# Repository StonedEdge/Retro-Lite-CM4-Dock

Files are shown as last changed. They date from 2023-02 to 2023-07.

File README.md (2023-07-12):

<div align="center">

# **Retro Lite CM4 AIO Docking Station**

</div>

<p align="center">
   
</p>
<p align="center">
   
</p>
<p align="center">
   
</p>

# Description 
Updated: 2023/07/09

Note: Code base is now functional in terms of splashscreen, statistics images and metadata with text wrap! 
I'm considering this project completed at this stage. Feel free to make improvements to it and use it in any way you'd like! 

-----------------------------------------------------------------------------------------------------------

The Retro Lite CM4 docking station/hub is designed to be used with the Retro Lite CM4 gaming console however will work on any generic Linux host running RetroPie. 
The main goal of this project is to act as a metadata box for your RetroPie system & learn more about the games you are playing in real time - the aim is to preserve a small part of retro gaming history through this project. The project boasts the following features:

- Fully integrated 1.5" 128x128 SPI driven 16-bit color display 
- 3 modes, including **splashscreen**, **stats** and **game** mode. Navigation is done using a push button connected to a GPIO pin
- 3 x external USB 2.0 ports to use for keyboard, mouse & other peripherals in desktop mode. USB controller compatible for low latency
- USB-C charging 
- HDMI video output 

Here is the general flow of the program and how it works when power is applied:

1) **Splashscreen mode**
   - Splashscreen is played until EmulationStation starts. After which, stats mode is entered
2) **Stats mode**
   - Shows general system statistics - IP address, SoC temperature, RAM usage, etc. Stats are updated in 5 second intervals
   - Retro stats - see your systems overall top 5 games played by (a) duration and (b) times played 
3) **Game mode**
   - Shows a combined image of the game being played on launch of any game
   - Cycle through 5 different metadata views via the push button attached to the docking station. These are: 

         a) Combined vector image of wheel and screenshot

         b) Official game boxart

         c) A randomized vector image of the real hardware the game could be played on. Includes all variants of every console (shoutouts to Ampersand for providing the high quality vectors!)

         d) A description of the game, which scrolls vertically along the display

         e) Other metadata, including rating, release date, developer, publisher, genre & # players per game 

# Installation
To install, run (won't currently work yet!)
```
git clone https://github.com/StonedEdge/Retro-Lite-CM4-Dock.git
sudo chmod +x install_dock.sh
./ install_dock.sh
```

I recommend scraping your media files via the inbuilt scraper in the RetroPie setup script menus. This will download all of the metadata required and automatically store it in /home/pi/RetroPie/roms/{system_name}/media. 

# Metadata directory locations 

a) **Current game cover (boxart)** - /opt/retropie/configs/all/emulationstation/downloaded_images/{system}/{rom_name}.png

b) **Screenshot + combined wheel image** - /home/pi/retropie/roms/{system}/media/wheel/{rom_name}.png && /home/pi/retropie/roms/{system}/media/screenshot/{rom_name}.png

c) **Randomized vector images of console released** - /home/pi/pico/pico-examples/pico-spi/consolevectors

d) **Game description using vertical scrolling** - /opt/retropie/configs/all/emulationstation/gamelists', system_name, 'gamelist.xml'

e) **Game developer** - /opt/retropie/configs/all/emulationstation/gamelists', system_name, 'gamelist.xml' 

f) **Release date** - /opt/retropie/configs/all/emulationstation/gamelists', system_name, 'gamelist.xml'

g) **Videos** - /home/pi/retropie/roms/{system}/media/videos/{rom_name}.mp4

# Hardware 
Image of Retro Lite CM4

Pinout to connect the OLED screen to the docking station is located above. Gerbers and CAD (both docking station and separate OLED box) files will be updated soon once the software is completed. 

# To-do
- [x] Detect current game/system booted using `runcommand`
- [x] Add Retrolite CM4 splashscreen on boot 
- [x] Downscale + convert screenshot and wheel images to 128x128 RGB565 on Pi 4 (Python)
- [x] Detect RP2040 by Product/Vendor IDs (VID/PIDs)  
- [x] Identify how to extract game text metadata using Python 
- [x] Send system stats to RP2040 over USB 
- [x] Clear buffer when runcommand-onend.sh is executed when a game is closed, bringing back user to Pi stats view
- [x] Stop splashscreen on COM port detect and switch to stats mode
- [x] Send over RGB565 combined.png over serial without corruption, automatic switching from Pi stats to current game
- [x] Write a python script to scale the boxart correctly to fit the screen
- [x] Send over random image to Pico located in consolevectors based on current system being launched on RetroPie (no scaling necessary)
- [x] Implement a button state machine to switch between the stats and image mode
- [x] Implement a timeout which fades black to the OLED with no button input. Wake up OLED on button press after X mins of no activity 
- [x] Implement game metadata within game mode
- [x] Gracefully shutdown the OLED display when the console is powered down and restart it when console is repowered on
- [x] Identify how to perform hardware (or software) vertical scrolling of text on the SSD1351 for game descriptions 
- [x] Fix some new line errors in metadata mode 
- [x] Figure out how to encode special characters - probably via European code pages (CP1250/1252)

# Nice to have/probably won't implement any time soon! 
- [ ] Write a python script to break up video into individual video frames on the Pi 4 
- [ ] Setup tinyUSB library to try and achieve 0.9MB/s transfer speeds for all frames, for 30 FPS video over USB 1.1 (max 1.5MB/s)
- [ ] Implement "retrostats" into stats mode to show user most played games by **times played** & **time duration** using the RetroStats scripts. Note : No RTC so time duration may not be accurate.

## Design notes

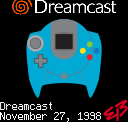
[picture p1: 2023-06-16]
consolevectors/dreamcast/Dreamcast - Electronics Botique.png

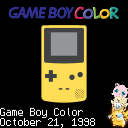
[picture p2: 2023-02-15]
consolevectors/gbc/Game Boy Color - Special Pikachu Edition.png

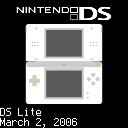
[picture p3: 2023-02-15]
consolevectors/nds/Nintendo DS Lite - White.png

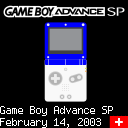
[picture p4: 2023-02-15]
consolevectors/gba/GBA SP -Swarovski (US).png

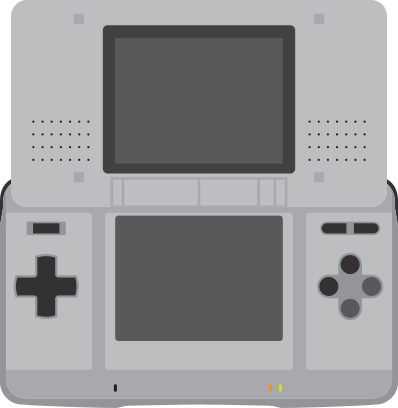
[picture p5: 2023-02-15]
consolevectors/nds/DS.png

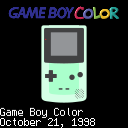
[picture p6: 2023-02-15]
consolevectors/gbc/Game Boy Color - Clear Green (Toys 'R' Us, Japan, 2000).png

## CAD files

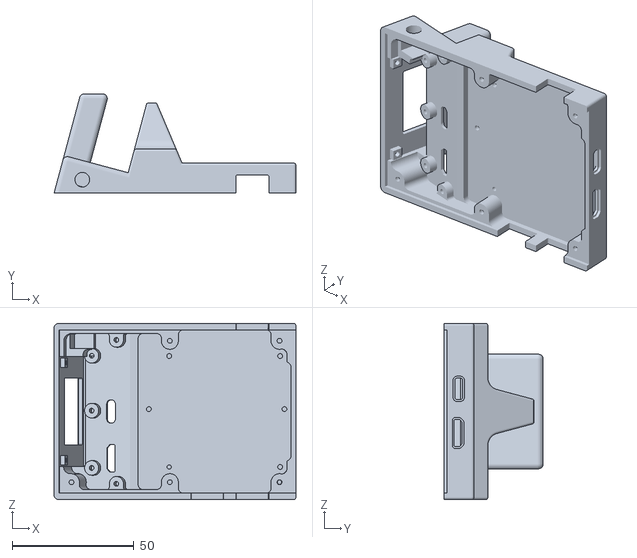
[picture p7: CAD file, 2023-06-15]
CAD/Dock - Main Housing.stl
99.2 x 40.8 x 72.3

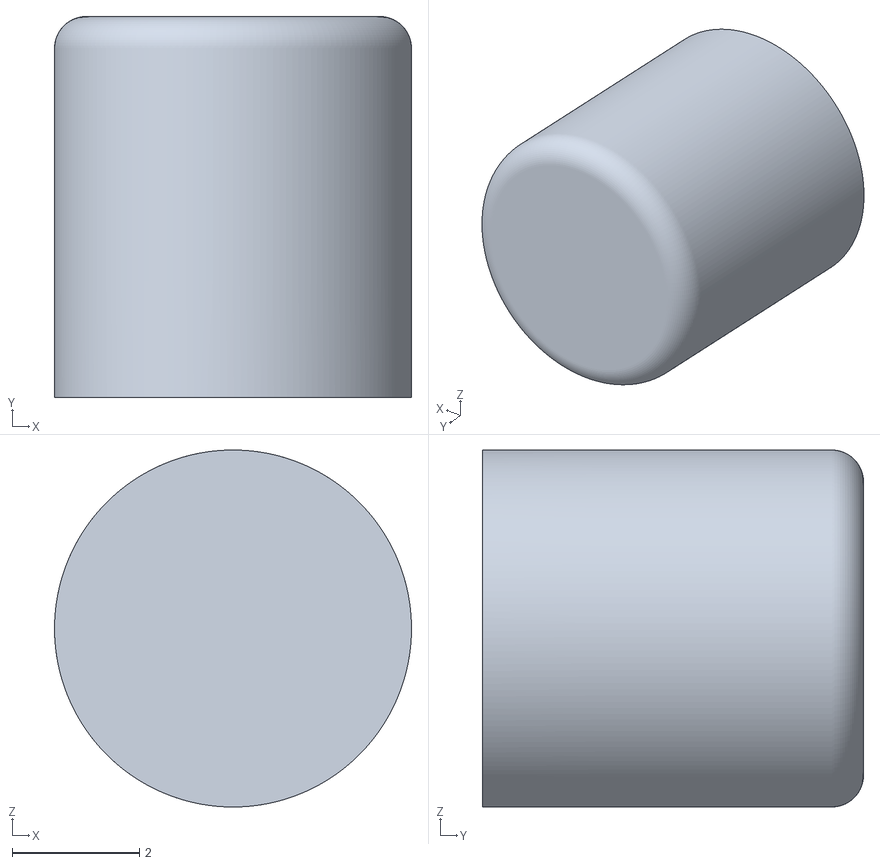
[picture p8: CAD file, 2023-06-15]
CAD/Button.stl
5.62 x 6.00 x 5.62

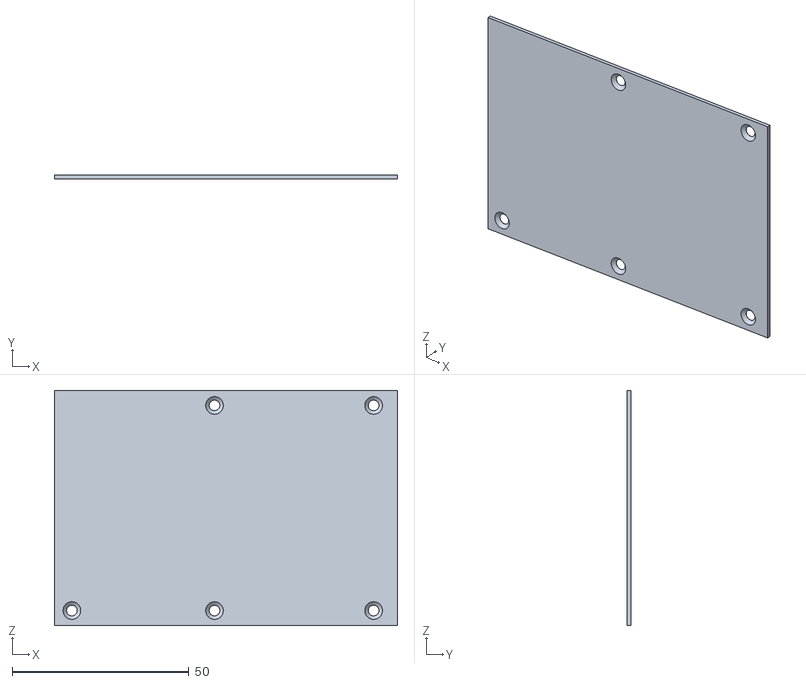
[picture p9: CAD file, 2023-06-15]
CAD/Lid.stl
97.0 x 1.05 x 66.6

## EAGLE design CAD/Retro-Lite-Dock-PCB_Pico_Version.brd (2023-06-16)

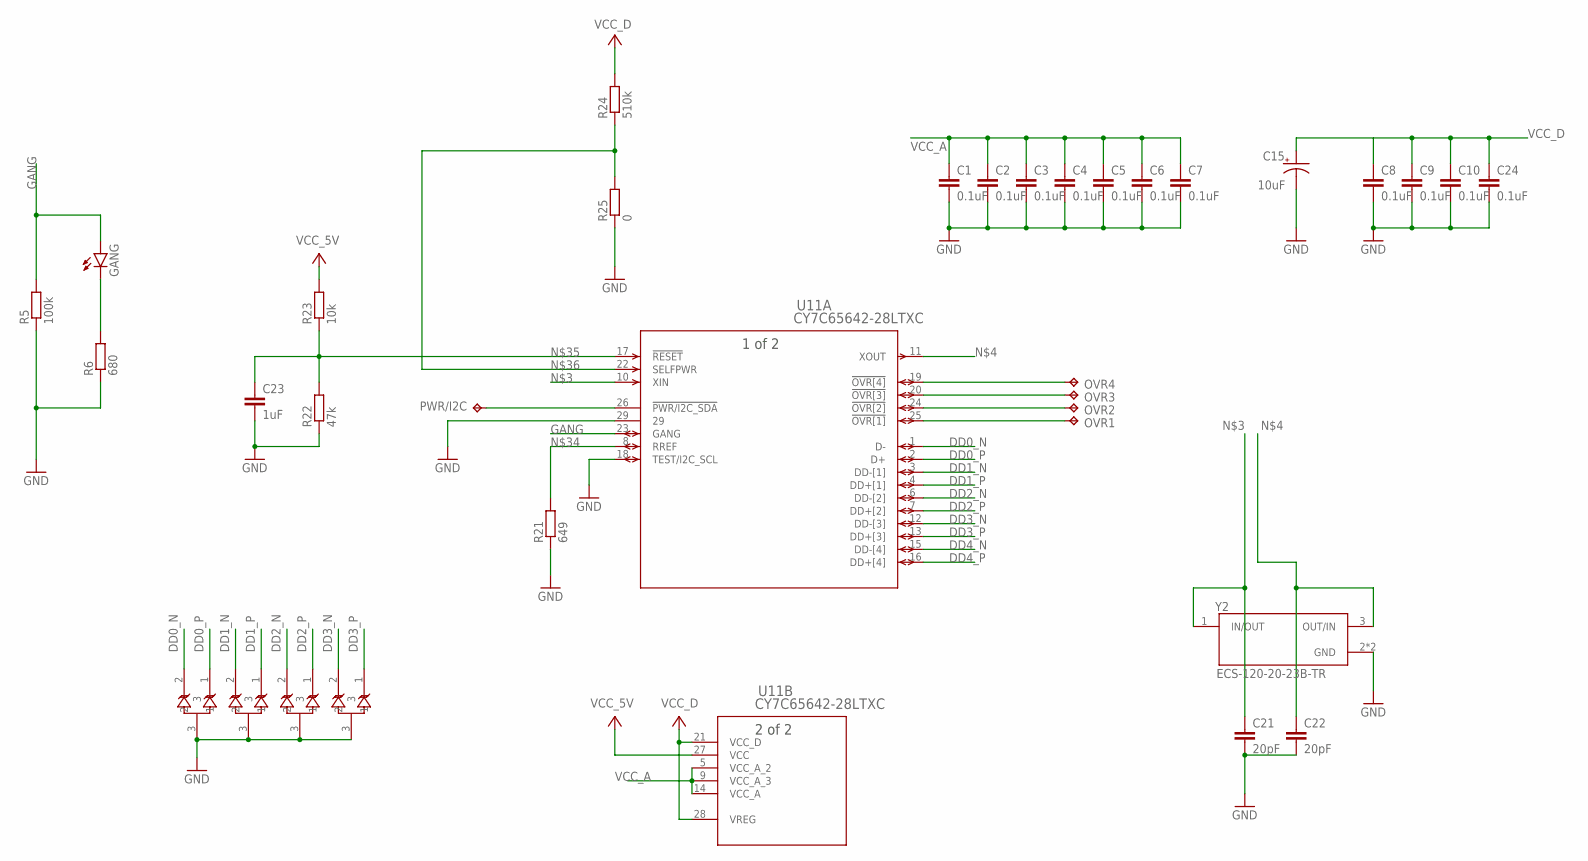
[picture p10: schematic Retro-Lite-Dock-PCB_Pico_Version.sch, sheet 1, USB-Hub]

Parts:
C1, C2, C3, C4, C5, C6, C7, C8, C9, C10, C24: 0.1uF; C0603
C15: 10uF; CAPAE660X610
C21, C22: 20pF; C0603
C23: 1uF; C0603
GANG: LEDSML0603; SML0603
OVR1, OVR2, OVR3, OVR4: TPTP09R; TP09R
PWR/I2C: TPTP09R; TP09R
R5: 100k; R0603
R6: 680; R0603
R21: 649; R0603
R22: 47k; R0603
R23: 10k; R0603
R24: 510k; R0603
R25: 0; R0603
U2, U3, U4, U10: RCLAMP0582BQTCT; SC75-3L_SEM
U11: CY7C65642-28LTXC; QFN-28
Y2: ECS-120-20-23B-TR; XTAL_ECS-120-20-23B-TR

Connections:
DD0_N: U10.2, U11.1 (D-); also elsewhere on the board
DD0_P: U10.1, U11.2 (D+); also elsewhere on the board
DD1_N: U2.2, U11.3 (DD-[1]); also elsewhere on the board
DD1_P: U2.1, U11.4 (DD+[1]); also elsewhere on the board
DD2_N: U3.2, U11.6 (DD-[2]); also elsewhere on the board
DD2_P: U3.1, U11.7 (DD+[2]); also elsewhere on the board
DD3_N: U4.2, U11.12 (DD-[3]); also elsewhere on the board
DD3_P: U4.1, U11.13 (DD+[3]); also elsewhere on the board
DD4_N: U11.15 (DD-[4]); also elsewhere on the board
DD4_P: U11.16 (DD+[4]); also elsewhere on the board
GANG: GANG.A, R5.2, U11.23 (GANG)
GND: C1.2, C2.2, C3.2, C4.2, C5.2, C6.2, C7.2, C8.2, C9.2, C10.2, C15.2 (-), C21.2, C22.2, C23.2, C24.2, R5.1, R6.1, R21.1, R22.1, R25.1, U2.3, U3.3, U4.3, U10.3, U11.18 (TEST/I2C_SCL), U11.29, Y2.2 (GND), Y2.4 (GND); also elsewhere on the board
unnamed: GANG.C, R6.2
unnamed: C21.1, U11.10 (XIN), Y2.1 (IN/OUT)
unnamed: C22.1, U11.11 (XOUT), Y2.3 (OUT/IN)
unnamed: OVR1.TP, U11.25 (!OVR[1])
unnamed: OVR2.TP, U11.24 (!OVR[2])
unnamed: OVR3.TP, U11.20 (!OVR[3])
unnamed: OVR4.TP, U11.19 (!OVR[4])
unnamed: R21.2, U11.8 (RREF)
unnamed: C23.1, R22.2, R23.1, U11.17 (!RESET)
unnamed: R24.1, R25.2, U11.22 (SELFPWR)
PWR/I2C_SDA: PWR/I2C.TP, U11.26 (!PWR/I2C_SDA)
VCC_5V: R23.2, U11.27 (VCC); also elsewhere on the board
VCC_A: C1.1, C2.1, C3.1, C4.1, C5.1, C6.1, C7.1, U11.5 (VCC_A_2), U11.9 (VCC_A_3), U11.14 (VCC_A); also elsewhere on the board
VCC_D: C8.1, C9.1, C10.1, C15.1 (+), C24.1, R24.2, U11.21 (VCC_D), U11.28 (VREG); also elsewhere on the board

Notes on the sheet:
10uF

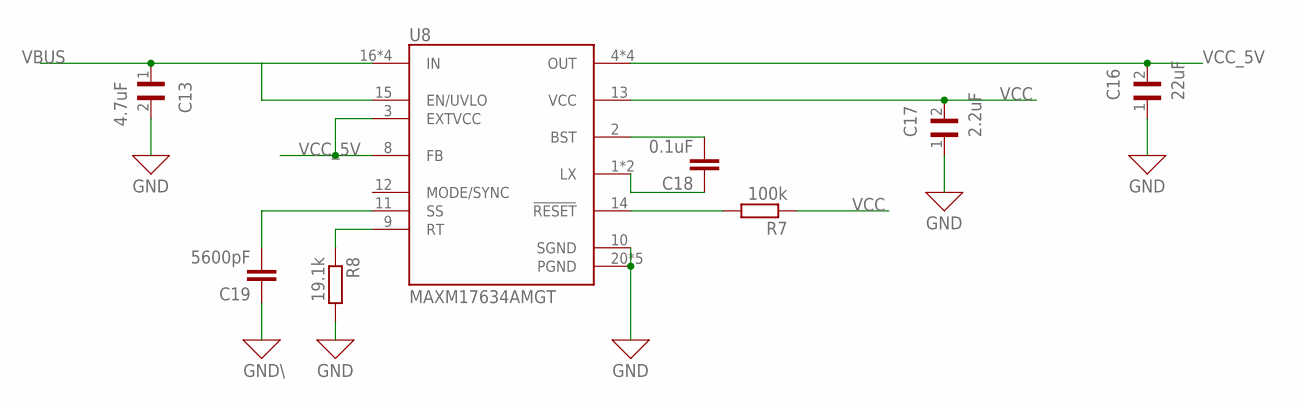
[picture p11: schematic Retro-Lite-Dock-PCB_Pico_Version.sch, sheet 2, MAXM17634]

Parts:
C13: 4.7uF; CAPC3216X180N
C16: 22uF; CAPC3225X270N
C17: 2.2uF; CAPC1608X90N
C18: 0.1uF; C0603
C19: 5600pF; C0603
R7: 100k; R0603
R8: 19.1k; R0603
U8: MAXM17634AMGT; QFN50P400X400X180-25N

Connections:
GND: C13.2, C16.1, C17.1, R8.2, U8.10 (SGND), U8.20 (PGND), U8.21 (PGND), U8.22 (PGND), U8.23 (PGND), U8.25 (PGND); also elsewhere on the board
GND\: C19.1
unnamed: R7.2, U8.14 (!RESET!)
unnamed: C18.2, U8.2 (BST)
unnamed: C18.1, U8.1 (LX), U8.24 (LX)
unnamed: C19.2, U8.11 (SS)
unnamed: R8.1, U8.9 (RT)
VBUS: C13.1, U8.15 (EN/UVLO), U8.16 (IN), U8.17 (IN), U8.18 (IN), U8.19 (IN); also elsewhere on the board
VCC: C17.2, R7.1, U8.13 (VCC)
VCC_5V: C16.2, U8.3 (EXTVCC), U8.4 (OUT), U8.5 (OUT), U8.6 (OUT), U8.7 (OUT), U8.8 (FB); also elsewhere on the board

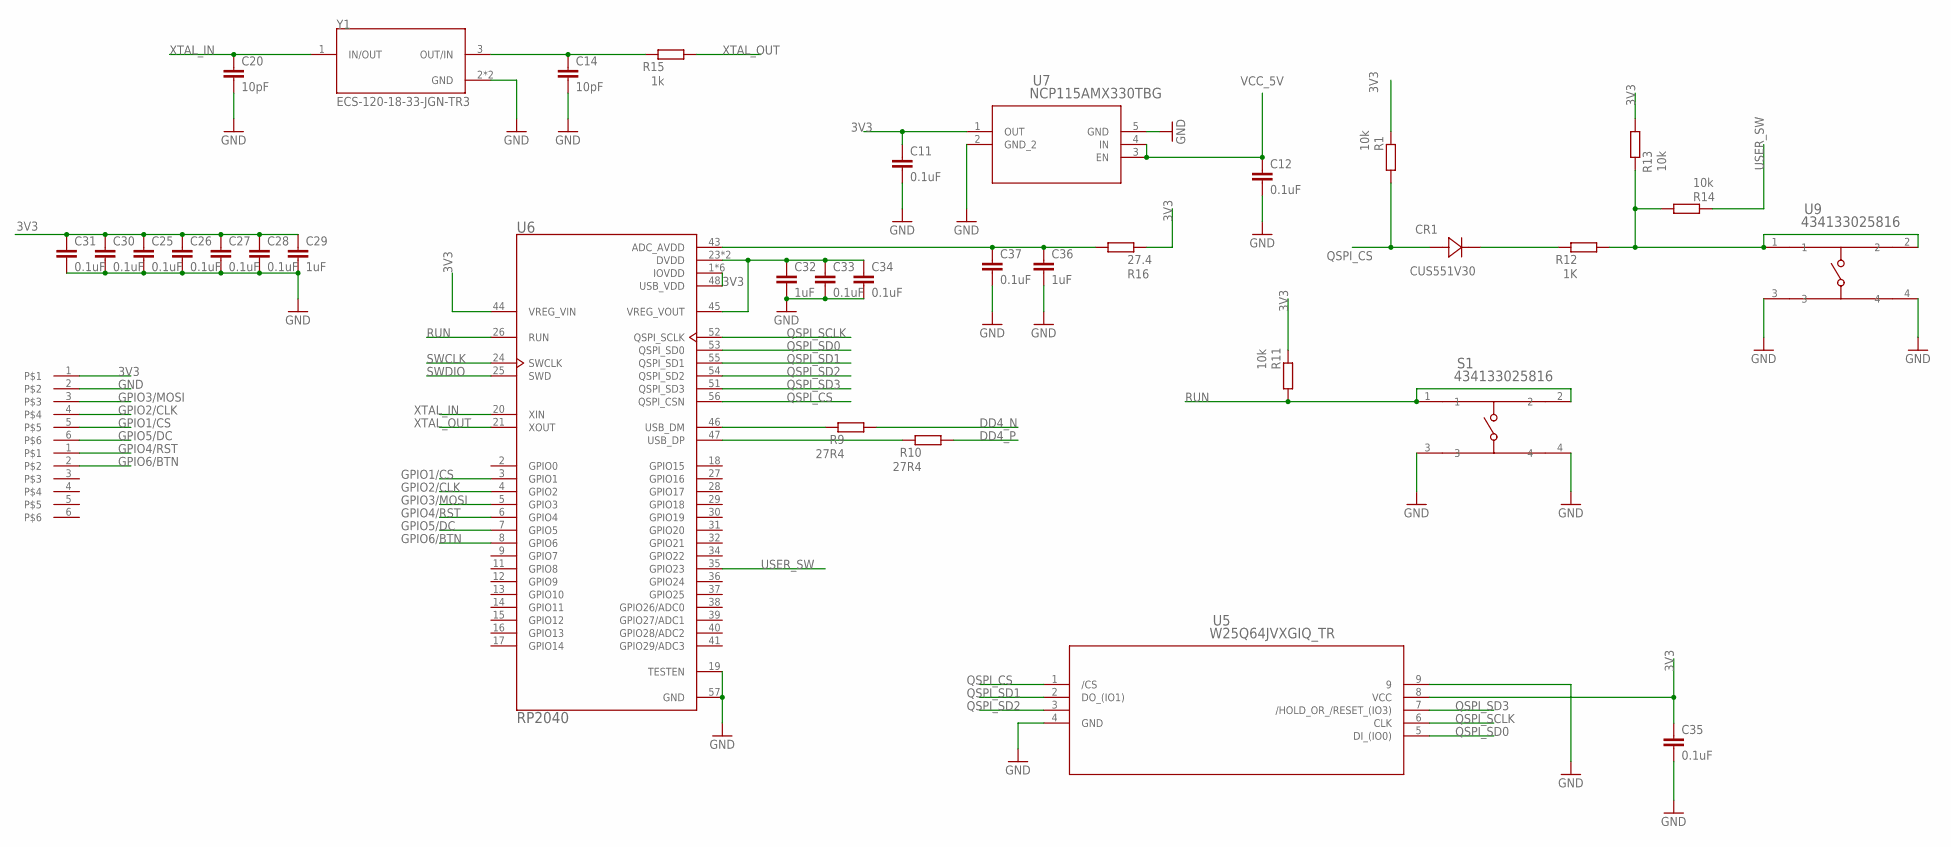
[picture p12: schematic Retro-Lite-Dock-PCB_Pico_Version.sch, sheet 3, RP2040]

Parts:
C11, C12, C25, C26, C27, C28, C31, C34, C35: 0.1uF; C0603
C14, C20: 10pF; C0603
C29, C36: 1uF; C0402
C30, C33, C37: 0.1uF; C0402
C32: 1uF; C0603
CR1: CUS551V30; USC_TOS
R1, R11, R13, R14: 10k; R0603
R9, R10: 27R4; R0402
R12: 1K; R0603
R15: 1k; R0402
R16: 27.4; R0402
S1: 434133025816; SMD_025816_WRE
U5: W25Q64JVXGIQ_TR; DFN_XGIQ_TR_WIN
U6: RP2040; QFN40P700X700X90-57N
U7: NCP115AMX330TBG; XDFN4_711AJ_ONS
U9: 434133025816; SMD_025816_WRE
U$2, U$3: 6PINEADER; 1MM_PIC-PROGRAMING_HEADER
Y1: ECS-120-18-33-JGN-TR3; XTAL_ECS-120-18-33-JGN-TR3

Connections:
3V3: C11.1, C25.1, C26.1, C27.1, C28.1, C29.1, C30.1, C31.1, C35.1, R1.2, R11.2, R13.1, R16.2, U5.8 (VCC), U6.1 (IOVDD), U6.10 (IOVDD), U6.22 (IOVDD), U6.33 (IOVDD), U6.42 (IOVDD), U6.44 (VREG_VIN), U6.48 (USB_VDD), U6.49 (IOVDD), U7.1 (OUT), U$3.1
DD4_N: R9.1; also elsewhere on the board
DD4_P: R10.1; also elsewhere on the board
GND: C11.2, C12.2, C14.2, C20.2, C25.2, C26.2, C27.2, C28.2, C29.2, C30.2, C31.2, C32.2, C33.2, C34.2, C35.2, C36.2, C37.2, S1.3, S1.4, U5.4 (GND), U5.9, U6.19 (TESTEN), U6.57 (GND), U7.2 (GND_2), U7.5 (GND), U9.3, U9.4, U$3.2, Y1.2 (GND), Y1.4 (GND); also elsewhere on the board
GPIO1/CS: U6.3 (GPIO1), U$3.5
GPIO2/CLK: U6.4 (GPIO2), U$3.4
GPIO3/MOSI: U6.5 (GPIO3), U$3.3
GPIO4/RST: U6.6 (GPIO4), U$2.1
GPIO5/DC: U6.7 (GPIO5), U$3.6
GPIO6/BTN: U6.8 (GPIO6), U$2.2
unnamed: C32.1, C33.1, C34.1, U6.23 (DVDD), U6.45 (VREG_VOUT), U6.50 (DVDD)
unnamed: R9.2, U6.46 (USB_DM)
unnamed: R10.2, U6.47 (USB_DP)
unnamed: R12.1, R13.2, R14.1, U9.1, U9.2
unnamed: C14.1, R15.2, Y1.3 (OUT/IN)
unnamed: C36.1, C37.1, R16.1, U6.43 (ADC_AVDD)
unnamed: CR1.1 (CATHODE), R12.2
QSPI_CS: CR1.2 (ANODE), R1.1, U5.1 (/CS), U6.56 (QSPI_CSN)
QSPI_SCLK: U5.6 (CLK), U6.52 (QSPI_SCLK)
QSPI_SD0: U5.5 (DI_(IO0)), U6.53 (QSPI_SD0)
QSPI_SD1: U5.2 (DO_(IO1)), U6.55 (QSPI_SD1)
QSPI_SD2: U5.3 (/WP_(IO2)), U6.54 (QSPI_SD2)
QSPI_SD3: U5.7 (/HOLD_OR_/RESET_(IO3)), U6.51 (QSPI_SD3)
RUN: R11.1, S1.1, S1.2, U6.26 (RUN)
SWCLK: U6.24 (SWCLK); also elsewhere on the board
SWDIO: U6.25 (SWD); also elsewhere on the board
USER_SW: R14.2, U6.35 (GPIO23)
VCC_5V: C12.1, U7.3 (EN), U7.4 (IN); also elsewhere on the board
XTAL_IN: C20.1, U6.20 (XIN), Y1.1 (IN/OUT)
XTAL_OUT: R15.1, U6.21 (XOUT)

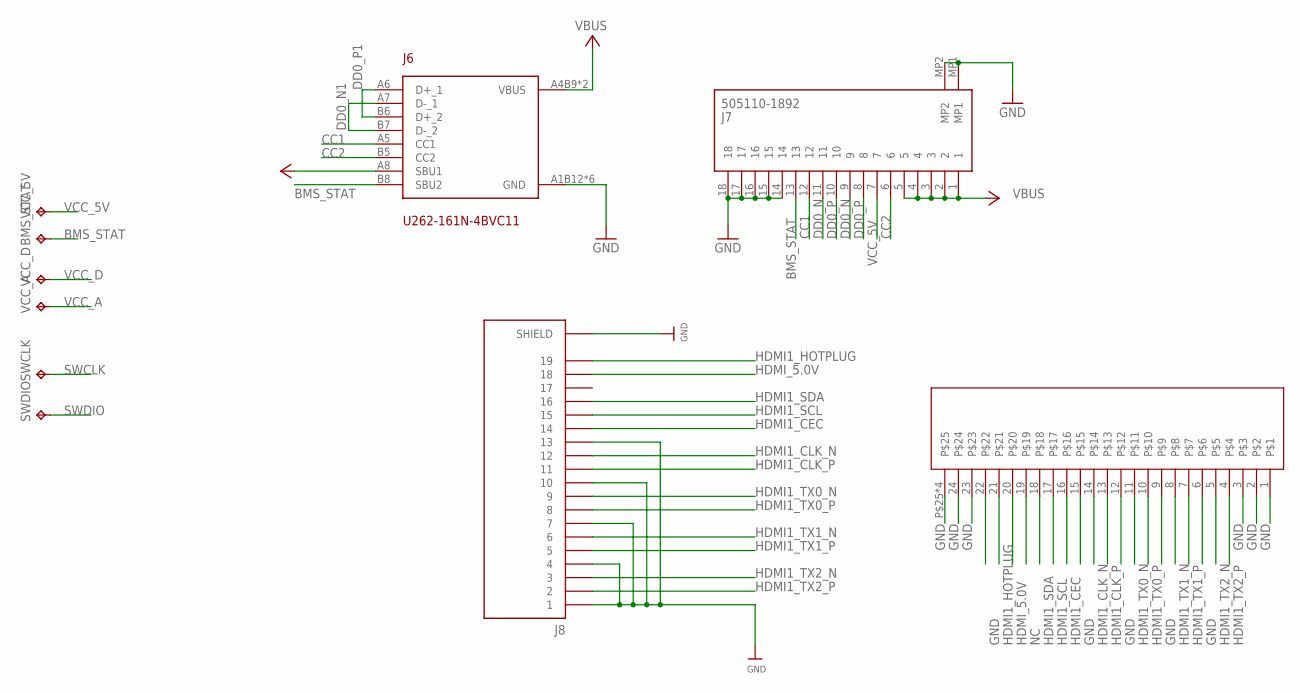
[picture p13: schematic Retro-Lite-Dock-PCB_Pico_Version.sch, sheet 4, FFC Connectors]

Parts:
BMS_STAT: TPTP09R; TP09R
J6: U262-161N-4BVC11
J7: 505110-1892; 5051101892
J8: 685119136923; WURTH_685119136923
SWCLK: TPTP09R; TP09R
SWDIO: TPTP09R; TP09R
U$1: 5022442430_FFC; 5022442430
VCC_5V: TPTP09R; TP09R
VCC_A: TPTP09R; TP09R
VCC_D: TPTP09R; TP09R

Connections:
BMS_STAT: BMS_STAT.TP, J6.B8 (SBU2), J7.13
CC1: J6.A5 (CC1), J7.12
CC2: J6.B5 (CC2), J7.6
DD0_N: J7.9, J7.11; also elsewhere on the board
DD0_N1: J6.A7 (D-_1), J6.B7 (D-_2)
DD0_P: J7.8, J7.10; also elsewhere on the board
DD0_P1: J6.A6 (D+_1), J6.B6 (D+_2)
GND: J6.A1B12 (GND), J6.B1A12 (GND), J6.SHIELD_1 (GND), J6.SHIELD_2 (GND), J6.SHIELD_3 (GND), J6.SHIELD_4 (GND), J7.14, J7.15, J7.16, J7.17, J7.18, J7.MP1, J7.MP2, J8.1, J8.4, J8.7, J8.10, J8.13, J8.S1 (SHIELD), J8.S2 (SHIELD), J8.S3 (SHIELD), J8.S4 (SHIELD), U$1.1, U$1.2, U$1.3, U$1.6, U$1.9, U$1.12, U$1.15, U$1.22, U$1.23, U$1.24, U$1.P$25, U$1.P$26, U$1.P$27, U$1.P$28; also elsewhere on the board
HDMI1_CEC: J8.14, U$1.16
HDMI1_CLK_N: J8.12, U$1.14
HDMI1_CLK_P: J8.11, U$1.13
HDMI1_HOTPLUG: J8.19, U$1.21
HDMI1_SCL: J8.15, U$1.17
HDMI1_SDA: J8.16, U$1.18
HDMI1_TX0_N: J8.9, U$1.11
HDMI1_TX0_P: J8.8, U$1.10
HDMI1_TX1_N: J8.6, U$1.8
HDMI1_TX1_P: J8.5, U$1.7
HDMI1_TX2_N: J8.3, U$1.5
HDMI1_TX2_P: J8.2, U$1.4
HDMI_5.0V: J8.18, U$1.20
NC: U$1.19
SWCLK: SWCLK.TP; also elsewhere on the board
SWDIO: SWDIO.TP; also elsewhere on the board
VBUS: J6.A4B9 (VBUS), J6.B4A9 (VBUS), J7.1, J7.2, J7.3, J7.4, J7.5; also elsewhere on the board
VCC_5V: J6.A8 (SBU1), J7.7, VCC_5V.TP; also elsewhere on the board
VCC_A: VCC_A.TP; also elsewhere on the board
VCC_D: VCC_D.TP; also elsewhere on the board

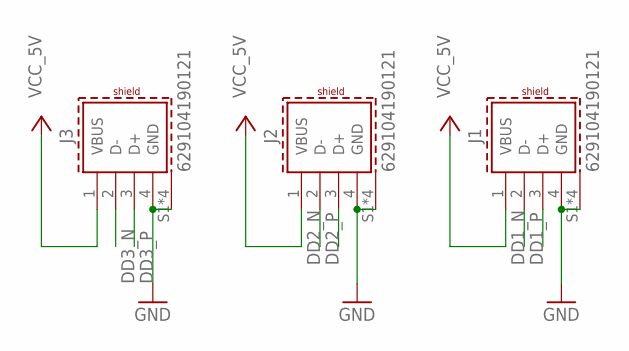
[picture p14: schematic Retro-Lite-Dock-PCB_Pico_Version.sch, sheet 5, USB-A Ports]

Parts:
J1, J2, J3: 629104190121

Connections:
DD1_N: J1.2 (D-); also elsewhere on the board
DD1_P: J1.3 (D+); also elsewhere on the board
DD2_N: J2.2 (D-); also elsewhere on the board
DD2_P: J2.3 (D+); also elsewhere on the board
DD3_N: J3.2 (D-); also elsewhere on the board
DD3_P: J3.3 (D+); also elsewhere on the board
GND: J1.4 (GND), J1.S1 (SHIELD), J1.S2 (SHIELD), J1.S3 (SHIELD), J1.S4 (SHIELD), J2.4 (GND), J2.S1 (SHIELD), J2.S2 (SHIELD), J2.S3 (SHIELD), J2.S4 (SHIELD), J3.4 (GND), J3.S1 (SHIELD), J3.S2 (SHIELD), J3.S3 (SHIELD), J3.S4 (SHIELD); also elsewhere on the board
VCC_5V: J1.1 (VBUS), J2.1 (VBUS), J3.1 (VBUS); also elsewhere on the board

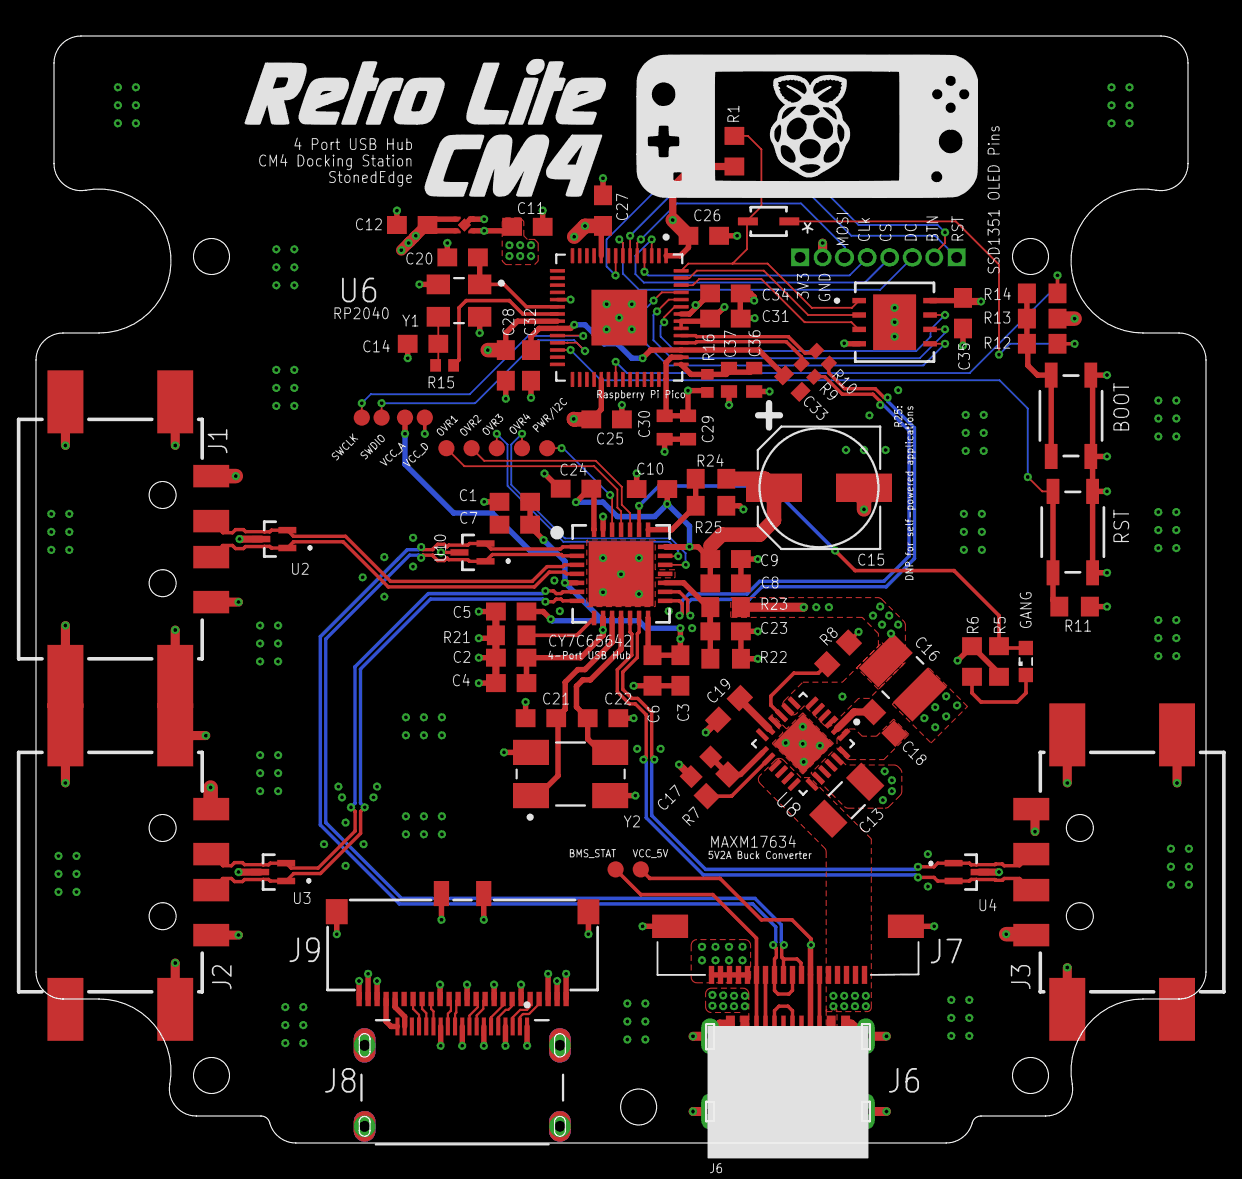
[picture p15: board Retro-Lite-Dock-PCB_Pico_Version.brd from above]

Board: 4 copper layers, 65.0 x 61.5 mm, 90 parts (0 on the bottom side), 77 nets.

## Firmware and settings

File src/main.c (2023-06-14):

/* Main.c -- Retro-Lite CM4 Docking Station -- Main code -- bdt -- 2023-01-01
* Copyright (c) 2023 Benjamin D. Todd.
*
* This is the main code that runs on a Raspberry Pi Pico.  The host is a Raspberry Pi, and
* the host logic is largely implemented in python.
* 
* License
* =======
* Creative Commons Attribution Share Alike 4.0 International*
*
* Revision History
* ================
* 2023-05-08 wmm  Restructure the serial input thread and main code so that input is handled in only a single thread.
* 
* 2023-05-10 wmm  Change python host code to generate .bin images use Big Endian encoding.  This way, reading the
*                 16-bit rgb 565 values will appear in the Pico in the proper order when reading the image stream
*                 as bytes.
* 
* 2023-05-15 wmm  Implement "screen blackout" after one minute of inactivity. If you are playing a game
*                 you can exit blackout mode by pressing the utility button.  Otherwise you must start a new game.
*                 
*                 (If you are in statistics display mode when blackout occurs, there is no way to exit blackout mode
*                 since this display loop does not interact with the utility button.)
* 
* 2023-05-16 wmm  Remove "previous statistics data" (comment out for now), and to cure the problem of pixel artifacts,
*                 modify SSD1351_write_char() to write all pixels in the font, not just non-black pixels.
* 
*            wmm  When waking up from screen blackout, display the current image instead of skipping to the next image.
*
* 2023-05-19 wmm  Added watchdog timer handling at the end of main().  Terminating main() will now reboot the processor
*                 intead of going ginto an infinite breakpoint loop.
*
* 2023-05-27 wmm  Fixed SSD1351_write_char -- It was setting all pixels, not just "non-empty" pixels.
* 
* 2023-05-31 wmm  Added "sudo" to python3 command in runcommand-onend.sh.
* 
* 2023-06-01 wmm  Restructured main() so it does initialization only once.  Apparently either the GPIO re-init or the
*                 various library inits are not possible and can result in the display of garbage and other funny
*                 behviour afer running our shutdown logic and then trying to restart.
* 
* 2023-06-01 wmm  Modified ssd1351 output routines to accept a color value containing both the foreground and background
*                 colors.  The default background color is black.
* 
*                 Always show splash screen at start of loop instead of splash screen on first pass, then stats display.
* 
* 2023-06-09 wmm  Added SSD1351_display_text_buffer.  The text is current fixed with some test data, but this will eventually
*                 come from the RPi host.
*
* 2023-06-12 wmm  Added more code to accept the game metadata from the RPi and then to display it via
*                 SSD13551_display_text_buffer.
* 
* Power Behavior
* ==============
+ TODO: Review these comments - do they all still apply?  2023-05-27.
* Let's assume the charger is always plugged in to the dock at the beginning but no console is connected to start.
*
* (Scenario 1) In the above state, no power is delivered on VBUS. The Pico is not powered and the battery is not charging. This is because the charger only is able to deliver VBUS power if it detects a sink controller. If the console is not plugged in, no power is delivered to the Pico. The Pico is powered by a step-down DC-DC converter which steps down VBUS voltage. No console, no power to the Pico, no power to the OLED.
*
* (Scenario 2) The user plugs in the console in a turned off state. Power is now delivered on VBUS and the code immediately runs as the Pico receives power. 
* The splashscreen will loop for approximately 30 seconds, and then display "NO CONNECTION".  If no connection is established after about one minute,
* the OLED shuts off.
*
* (Scenario 3) The console is in the dock now. The user turns on power to the console from an off state by holding the power button for 3 seconds.
* It takes about 15-20 seconds until EmulationStation process runs from a cold boot. The console will detect the process has begun and then switch over to stats mode.
*
* (Scenario 4) The user has enjoyed playing whatever game he wants to play and now decides its time for the console to be switched off. There's two ways he/she can do this. 
* The first way is by navigating within the RetroPie GUI and clicking "Power down". This will leave the regulator active but the software will be off. The second way is by holding 
* the power button for 3 seconds, after which a software shutdown will begin and then power to the regulator inside the console will be killed.
*
* (Scenario 5) The user decides to pull power directly from the back of the dock. In this case, the Pico does not cleanly shut down because power was immediately pulled. The console no longer charges and the OLED is now off, Pico is powered off, until the user plugs the USB-C charger back in to the dock.
*/

#include <stdlib.h>
#include <stdio.h>
#include <stdint.h>
#include <math.h>
#include <string.h>
#include <time.h>
#include <unistd.h>
#include <fcntl.h>
#include "pico/stdlib.h"
#include "pico/binary_info.h"
#include "pico/multicore.h"
#include "hardware/gpio.h"
#include "hardware/spi.h"
#include "hardware/watchdog.h"
#include "ssd1351.h"
#include "splash_vid.h"

#define BUTTON_PIN 6
#define DEBOUNCE_TIME_MS 100
#define IMAGE_SIZE_BYTES 32768
#define INACTIVE_TIMEOUT 60 * 1000000

// The worst case for an uncompressed IPV6 address would be 8 4-digit segments plus 7 colon separators + null, or 40 chars.
// I've reserved 64 characters just in case, although that would never fit in the tiny display.

#define STATS_BUFFER_SIZE 64

extern uint8_t buffer[OLED_BUF_SIZE];

uint8_t boxart_buffer[IMAGE_SIZE_BYTES] = { 0x00 };
uint8_t combined_buffer[IMAGE_SIZE_BYTES] = { 0x00 };
uint8_t consol_buffer[IMAGE_SIZE_BYTES] = { 0x00 };

// This is enough for about 50 lines of metadata text!

#define MAX_METADATA_LENGTH 2048

int metadata_buffer_length = 0;             // Actual length of received data.
char metadata_buffer[MAX_METADATA_LENGTH] = { 0 };

void EnableDisplay(bool enable);
bool GetLine(char* line, int lineSize);

typedef enum { SPLASH_SCREEN, GAME_ACTIVE, DISPLAY_STATS, DISPLAY_BLANKED } DISPLAY_MODE;
volatile DISPLAY_MODE displayMode = SPLASH_SCREEN;
volatile bool displayEnabled = false;   // The display is actually on after initialization, but set to false for EnableDisplay.
uint32_t lastActivityTime;              // Last activity in us

int shutdownReason = 0; // 0=No, 1=Power off, 2=Game Engine stopped.

                                        /**
* Display the various images in rotation while in "GAME_ACTIVE" mode.
*/

void ButtonLoop(void)
 {
    extern volatile bool displayEnabled;
    extern volatile DISPLAY_MODE displayMode;
    extern uint32_t lastActivityTime;
    extern char metadata_buffer[MAX_METADATA_LENGTH];
    extern int metadata_buffer_length;

    EnableDisplay(true);

    // The "start" handler initiallly displays the combined image.  Set current_display to 0
    // here, so on the first button press we'll increment and show the boxart.

    int current_display = 0;
    uint32_t last_press_time = 0;

    while (displayMode == GAME_ACTIVE) {
        if (!gpio_get(BUTTON_PIN)) {
            uint32_t currentTime = time_us_32();
            lastActivityTime = currentTime;

            if (currentTime - last_press_time >= DEBOUNCE_TIME_MS * 1000) {
                last_press_time = currentTime;

                // Button is pressed, cycle through the displays

                if (!displayEnabled) {      // If we are waking up, use the current item number.
                    EnableDisplay(true);
                }
                else if (++current_display > 3) {  // Rotate through the items.
                    current_display = 0;
                }

                switch (current_display) {
                    case 0:  // Display the combined image"
                        SSD1351_clear_8();
                        SSD1351_display_image(combined_buffer);
                        break;
                    case 1:  // Display the game metadata.
                        SSD1351_fill(COLOR_BLACK);                // Init the screen.
                        SSD1351_update();
                        SSD1351_set_cursor(0, 0);
                        SSD1351_display_text_buffer(metadata_buffer, metadata_buffer_length, COLOR_WHITE, small_font);
                        break;
                    case 2:  // Display the boxart image
                        SSD1351_clear_8();
                        SSD1351_display_image(boxart_buffer);
                        break;
                    case 3:  // Display the console image
                        SSD1351_clear_8();
                        SSD1351_display_image(consol_buffer);
                        break;
                }
            }
        }

        sleep_ms(10); // wait a short time before checking again

        if (time_us_32() - lastActivityTime >= INACTIVE_TIMEOUT) {
            EnableDisplay(false);
        }
    }
}

static char SD_usage[STATS_BUFFER_SIZE];    // A
static char CPU_temp[STATS_BUFFER_SIZE];    // B
static char CLK_speed[STATS_BUFFER_SIZE];   // C
static char RAM_usage[STATS_BUFFER_SIZE];   // D
static char IP_addr[STATS_BUFFER_SIZE];     // E

// The previous values are used so that we'll have something to init the display with on the first call when entering "X" mode.
// TODO: This claim is a bit funky - do we really need these?

#if 0  // 2023-05-16.  Disable.
char prev_SD_usage[STATS_BUFFER_SIZE];      // A
char prev_CPU_temp[STATS_BUFFER_SIZE];      // B
char prev_CLK_speed[STATS_BUFFER_SIZE];     // C
char prev_RAM_usage[STATS_BUFFER_SIZE];     // D
char prev_IP_addr[STATS_BUFFER_SIZE];       // E
#endif

/**
* Display statistics.
*
* The values are collected by the main thread, and we display them here once.
* 
* @caution This Code assumes that the messages are always the same length.  If so, no problem.  If not the
* messages could either overlap, or leave text from the previous iteration.
*/

void DisplayStats(void) {
    extern char SD_usage[STATS_BUFFER_SIZE], CPU_temp[STATS_BUFFER_SIZE], CLK_speed[STATS_BUFFER_SIZE], RAM_usage[STATS_BUFFER_SIZE], IP_addr[STATS_BUFFER_SIZE];
#if 0  // 2023-05-16.  Disable.
    extern char prev_SD_usage[STATS_BUFFER_SIZE], prev_CPU_tempSTATS_BUFFER_SIZE, prev_CLK_speed[STATS_BUFFER_SIZE], prev_RAM_usage[STATS_BUFFER_SIZE], prev_IP_addr[STATS_BUFFER_SIZE];
#endif
    const int r = 255;                  // Title colour
    const int g = 255;
    const int b = 255;

    const int r1 = 180;                 // Value colour
    const int g1 = 180;
    const int b1 = 180;

#if 0  // 2023-05-16.  Disable.
    // Clear Values

    SSD1351_set_cursor(5, 17);
    SSD1351_printf(SSD1351_get_rgb(0, 0, 0), small_font, prev_SD_usage);
    SSD1351_set_cursor(5, 42);
    SSD1351_printf(SSD1351_get_rgb(0, 0, 0), small_font, prev_CPU_temp);
    SSD1351_set_cursor(5, 67);
    SSD1351_printf(SSD1351_get_rgb(0, 0, 0), small_font, prev_CLK_speed);
    SSD1351_set_cursor(5, 92);
    SSD1351_printf(SSD1351_get_rgb(0, 0, 0), small_font, prev_RAM_usage);
    SSD1351_set_cursor(5, 117);
    SSD1351_printf(SSD1351_get_rgb(0, 0, 0), small_font, prev_IP_addr);

    strncpy(prev_SD_usage, SD_usage, strlen(SD_usage));
    strncpy(prev_CPU_temp, CPU_temp, strlen(CPU_temp));
    strncpy(prev_CLK_speed, CLK_speed, strlen(CLK_speed));
    strncpy(prev_RAM_usage, RAM_usage, strlen(RAM_usage));
    strncpy(prev_IP_addr, IP_addr, strlen(IP_addr));
#endif

    // Display Values
    SSD1351_set_cursor(5, 5);
    SSD1351_printf(SSD1351_get_rgb(r, g, b), small_font, "SD Usage");
    SSD1351_set_cursor(5, 17);
    SSD1351_printf(SSD1351_get_rgb(r1, g1, b1), small_font, SD_usage);
    SSD1351_set_cursor(5, 30);
    SSD1351_printf(SSD1351_get_rgb(r, g, b), small_font, "SoC Temp");
    SSD1351_set_cursor(5, 42);
    SSD1351_printf(SSD1351_get_rgb(r1, g1, b1), small_font, CPU_temp);
    SSD1351_set_cursor(5, 55);
    SSD1351_printf(SSD1351_get_rgb(r, g, b), small_font, "Clock Speed");
    SSD1351_set_cursor(5, 67);
    SSD1351_printf(SSD1351_get_rgb(r1, g1, b1), small_font, CLK_speed);
    SSD1351_set_cursor(5, 80);
    SSD1351_printf(SSD1351_get_rgb(r, g, b), small_font, "RAM Usage");
    SSD1351_set_cursor(5, 92);
    SSD1351_printf(SSD1351_get_rgb(r1, g1, b1), small_font, RAM_usage);
    SSD1351_set_cursor(5, 105);
    SSD1351_printf(SSD1351_get_rgb(r, g, b), small_font, "IP Address");
    SSD1351_set_cursor(5, 117);
    SSD1351_printf(SSD1351_get_rgb(r1, g1, b1), small_font, IP_addr);

    SSD1351_update();
}

/**
* Enable or disable the display.
* 
* On enable we also reset lastActivityTime, which is used for turning the display off after inactivity.
* 
* @param enable         [in] true to enable the display.
*/

void EnableDisplay(bool enable)
{
    extern volatile bool displayEnabled;
    extern uint32_t lastActivityTime;

    if (displayEnabled != enable) {
        displayEnabled = enable;

       if (enable) {
            SSD1351_write_command(SSD1351_CMD_FUNCTIONSELECT);  // Enable Vdd voltage regulator
            SSD1351_write_data(0x01);
            SSD1351_write_command(SSD1351_CMD_DISPLAYON);
        }
        else {
            // NOTE WELL:  You cannot write the display memory while the voltage regulator is off.

            SSD1351_write_command(SSD1351_CMD_DISPLAYOFF);
            SSD1351_write_command(SSD1351_CMD_FUNCTIONSELECT);  // Disable Vdd voltage regulator to save power
            SSD1351_write_data(0x00);
        }
    }

    if (enable) {  // Reset the last activity time elsewhere we can determine inactivity.
        lastActivityTime = time_us_32();
    }
}

/**
* Switch from current display mode to DISPLAY_STATS mode.
* 
* Called when we get the first "X" command and after an END command.
*/

void EnableDisplayStats()
{
    displayMode = DISPLAY_STATS;

    multicore_reset_core1();
    SSD1351_clear_8();
    SSD1351_update();
}

/**
* Read a line from stdin.
*
* @param line               [out] Output area.  Will contain null-terminated text without the newline character.
*
* @lineSize                 [in] Size of the the line area in bytes.  Must be > 1 !
*
* @return true if line read, false on EOF or error.
*/

bool GetLine(char* line, int lineSize)
{
    int lineIndex = 0;

    lineSize--;                         // Save space for final null.

    while (true) {
        int c = getchar();              // Pico version returns a uint8 value
        if (c < 0) {                    // STDIO_ERROR (-1) or STDIO_NO_INPUT (-2):  We are done.
            return false;
        }
        if (c == '\n') {                // Done.
            line[lineIndex] = '\0';
            return true;
        }
        else if (lineIndex < lineSize) {
            line[lineIndex++] = c;
        }
    }
}

/**
* Play the splash screen for up to 20 seconds.
* 
* @param splashTime (global)        [in] Display time (approx) in seconds.
*/

int splashTime = 20;
void PlaySplashVid(void) 
{
    const char* waitMsg = "Wait for Pi: %i ";  // MUST BE <= OLED_WIDTH AFTER FORMATTING AND FONT SIZE SCALE!

    EnableDisplay(true);

    int t = 0;
    while (t < splashTime) {
        SSD1351_write_command(SSD1351_CMD_WRITERAM);
        SSD1351_write_data_buffer(frame[0], OLED_BUF_SIZE);
        sleep_ms(500);
        for (int f = 1; f < FRAME_COUNT; f++) {
            SSD1351_write_command(SSD1351_CMD_WRITERAM);
            SSD1351_write_data_buffer(frame[f], OLED_BUF_SIZE);
            sleep_ms(10);
        }
        SSD1351_write_command(SSD1351_CMD_WRITERAM);
        SSD1351_write_data_buffer(frame[0], OLED_BUF_SIZE);
        sleep_ms(500);

        t++;
    }

    // Note uint8_t usage for lots of things in this code, and for message alignment don't go over a two-digit wait time.

    uint8_t wait_time = 30;
    uint8_t x = (OLED_WIDTH - strlen(waitMsg) * small_font.width) / 2;

    uint16_t fgColor  = SSD1351_get_rgb(255,255,255);  // White
    uint16_t bgColor = SSD1351_get_rgb(0,0,0);  // Black;
    SSD1351_fill(COLOR_BLACK);

    while (wait_time != 0) {
        SSD1351_set_cursor(x, 64);
        SSD1351_printf(COLORFGBG(fgColor, bgColor), small_font, waitMsg, wait_time);
        SSD1351_update();
        sleep_ms(1000);
        wait_time--;
    }

    // This thread is normally killed by the main control process upon receipt of an "X" command.  If that
    // still hasn't arrived, blank the display.

    EnableDisplay(false);
}

/**
* Play the splash screen video once.  (Not used.)
*/

void PlaySplashVidSingle(void) {
    EnableDisplay(true);

    SSD1351_write_command(SSD1351_CMD_WRITERAM);
    SSD1351_write_data_buffer(frame[0], OLED_BUF_SIZE);
    sleep_ms(500);
    for (int f = 1; f < FRAME_COUNT; f++) {
        SSD1351_write_command(SSD1351_CMD_WRITERAM);
        SSD1351_write_data_buffer(frame[f], OLED_BUF_SIZE);
        sleep_ms(10);
    }
    SSD1351_write_command(SSD1351_CMD_WRITERAM);
    SSD1351_write_data_buffer(frame[0], OLED_BUF_SIZE);
    sleep_ms(500);
}

/**
* Serial Input handler.
* 
* This routine is called from main().  It receives commands from the RPi host via the USB port,
* which we use to switch display modes.
* 
* This code runs on thread 0 (the main thread).  Thread 1 is used for the splash screen display
* and key monitorring.
*/
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
int main(void)
{
    extern volatile DISPLAY_MODE displayMode;
    bool done = false;
#if 0  // Pre 2023-06-02
    bool firstGame = true;
#endif
    extern int shutdownReason;
    extern int splashTime;

    // GPIO Set-Up

    // TODO: Will re-running these init calls work ok?

    spi_set_format(SPI_PORT, 8, SPI_CPOL_1, SPI_CPHA_1, SPI_MSB_FIRST);
    gpio_init(CS);
    gpio_set_dir(CS, GPIO_OUT);
    gpio_put(CS, 1);
    gpio_set_function(SCK, GPIO_FUNC_SPI);
    gpio_set_function(MOSI, GPIO_FUNC_SPI);
    gpio_pull_up(SCK);
    gpio_pull_up(MOSI);
    gpio_init(DC);
    gpio_set_dir(DC, GPIO_OUT);
    gpio_init(RST);
    gpio_set_dir(RST, GPIO_OUT);
    gpio_init(BUTTON_PIN);
    gpio_set_dir(BUTTON_PIN, GPIO_IN);
    gpio_pull_up(BUTTON_PIN);

    // SPI Initialisation

    stdio_init_all();
    spi_init(SPI_PORT, 15000000);
    SSD1351_init();

    if (!stdin) {  // We are screwed!
        SSD1351_clear_8();
        SSD1351_printf(SSD1351_get_rgb(255, 0, 0), small_font, "No Stdin!");
        SSD1351_update();
        sleep_ms(5000); // Display for a bit before we get to the watchdog timer code.
        done = true;
    }

    while (!done) {
        clearerr(stdin);

        // Set up the video thread

#if 1  // 2023-06-02  -- Always show splash screen.
        displayMode = SPLASH_SCREEN;
        multicore_launch_core1(PlaySplashVid);  // PlaySplashVid calls EnableDisplay.
#else
        if (firstGame) {
            displayMode = SPLASH_SCREEN;
            multicore_launch_core1(PlaySplashVid);  // PlaySplashVid calls EnableDisplay.
            firstGame = false;
        }
        else {
            displayMode = DISPLAY_BLANKED;  // Don't do anything until we get an 'X' command.
        }
#endif

        SerialThread();

        if (shutdownReason != 0) {
            multicore_reset_core1();
            SSD1351_clear_8();
            SSD1351_update();

            if (shutdownReason == 1) {
                // The Pico gets power from the VBUS, so there is always power unless you unplug the
                // docking station from the all.
                // 
                // We could go into dormant mode here to save power, but to exit dormant mode we would
                // need a pin to trigger wakeup, which we do not have.
                // 
                // Therefore, treat the power down event just like the emulator exit even.

                shutdownReason = 0;
            }
            else {
                shutdownReason = 0;             // Just restart the loop
            }
        }  // Otherwise we probably got here because of an I/O error.  Hopefully re-init will fix it.

        splashTime = 5;  // Shorten the splash screen display time after the first pass.
    }

    /*
    * Returning will lead you to exit(), and this can have one of two behaviors:
    * 
    * (1) If PICO_ENTER_USB_BOOT_ON_EXIT was set duriing build, the PICO will reboot.  This build option
    * is off by default.
    * 
    * (2) If not set, you will be in an endless _breakpoint() loop.  This is pretty useless unless you are
    * running the debugger since you will then need to power down and power up to continue.
    * 
    * Therefore, below we turn on the watchdog timer and enter an infinite loop.  After a moment the
    * watchdog timer will detect the loop and reset the processor.
    * 
    * PRESENTLY THERE IS NO WAY TO GET HERE UNLESS STDIN IS NOT DEFINED.  Shutdown1 waits above for power off, and Shutdown2 tries to restart
    * the loop abov.  However, leave this code for reference.
    */

    watchdog_enable(1, 1);
    while (1);

    return 0;  // Never reached
}

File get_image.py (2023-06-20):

#!/usr/bin/python3

from lib2to3.pgen2 import pgen
from operator import truediv
from pickle import TRUE
import subprocess
import serial
from serial import tools
from serial.tools import list_ports
import sys
import time
import os
import struct
import linecache
import xml.etree.ElementTree as et
import xml.sax.saxutils as saxutils
import cv2
import psutil
import fcntl
import random
import xml.etree.ElementTree as et
from difflib import SequenceMatcher
from PIL import Image, ImageDraw

displayWidth = 128                          # Same as OLED_WIDTH
charsPerLine = displayWidth // 7            # 18 chars per line (7 is small_font width)

def center_crop(img,dim):
	width, height = img.shape[1], img.shape[0]
	crop_width = dim[0] if dim[0]<img.shape[1] else img.shape[1]
	crop_height = dim[1] if dim[1]<img.shape[0] else img.shape[0]
	start_x = (width - crop_width) // 2
	start_y = (height - crop_height) // 2
	return img[start_y:start_y+crop_height, start_x:start_x+crop_width]

def get_img_directories():
	global wheel, screenshot, boxart, consol
	tempFile = open('/tmp/retropie-oled.log', 'r', -1)    # , "utf-8")
	retropie_oled_img_dir = tempFile.readlines()
	tempFile.close()
	screenshot = retropie_oled_img_dir[0].rstrip('\n')
	wheel = retropie_oled_img_dir[1].rstrip('\n')
	boxart = retropie_oled_img_dir[2].rstrip('\n')
	consol = retropie_oled_img_dir[3].rstrip('\n')


# Returns game meta data as a blob of lines.
#
# @param text               [in] Block of text to split.
#
# @param maxChars           [in] Maximum characters per line.
#
# @return An array of word-wrapped lines.

def word_wrap_text(text, maxChars):
    words = text.split()  # Split the text into individual words
    lines = []
    currentLine = ""

    wordIndex = 0
    for word in words:
        # Calculate the width of the current line if the word is added

        wordLen = len(word)
        currentLineLen = len(currentLine)

        while wordLen > 0:
            if wordLen >= maxChars:  # Extreme case:  Word is wider than output area.
                # Save current line if any, and put what will fit of the current word on its own line.

                if currentLineLen > 0:
                    lines.append(currentLine)
                lines.append(word[0:maxChars])  # This new line is full already.

                word = word[maxChars:]      # Keep splitting the remainder of this word
                wordLen = len(word)
                currentLineLen = 0
                currentLine = ""
            else:
                freeChars = maxChars - currentLineLen
                if currentLineLen != 0:
                    freeChars -= 1          # We'll also need a space before the word

                if wordLen <= freeChars:    # Word WILL fit on current line
                    if currentLineLen != 0:
                        currentLine += " "
                    currentLine += word
                else:                       # Word won't fit, start new line
                    if currentLineLen > 0:
                        lines.append(currentLine)
                    currentLine = word      # This word starts on a new line.
                wordLen = 0                 # Clear to get out of while loop

    if currentLine != "":  # Add the last line if there are remaining words
        lines.append(currentLine)

    return lines

# Returns game meta data as a blob of lines.

def get_game_metadata():
    tempFile = open('/tmp/retropie-oled.log', 'r', -1, "utf-8")
    gameMetadata = tempFile.readlines()
    tempFile.close()
    game_name = gameMetadata[0].split('/')[-1].rsplit('.', 1)[0].split('(')[0].rstrip()  # Get the current game name
    system_name = gameMetadata[0].split('/')[5]  # Get the current system name
    gamelist_path = os.path.join('/opt/retropie/configs/all/emulationstation/gamelists', system_name, 'gamelist.xml')
    data = et.parse(gamelist_path)

    gameMetadata = ''
    gameMetadataDesc = ''
    
    gameMetadata += 'Game Name: ' + '\n' + game_name + '\n'
    gameMetadata += 'System Name: ' + '\n' + system_name + '\n'

    game_list = data.findall(u".//game[name='{0}']".format(saxutils.escape(game_name)))

    desc = 'No description found'
    release_date = 'No release date found'
    developer = 'No developer found'
    publisher = 'No publisher found'
    genre = 'No genre found'

    # Find the best matching game name in the XML tree
    best_match_ratio = 0.0
    best_match_game = None
    
    for game in data.findall(".//game"):
        name = game.find('name').text
        match_ratio = SequenceMatcher(None, game_name, name).ratio()
        
        if match_ratio > best_match_ratio:
            best_match_ratio = match_ratio
            best_match_game = game
    
    if best_match_game is not None:
        # Extract the desired information from the best matching game element
        if best_match_game.find('desc') is not None:
            temp = str(best_match_game.find('desc').text)
            desc = str(temp)
            gameMetadataDesc += desc + '\n'
        else:
            desc = 'N/A'
        print(desc)

        if best_match_game.find('releasedate') is not None:
            temp = str(best_match_game.find('releasedate').text)
            if len(temp) >= 8:  # Split out Year-Month-Day from ISO data.
                temp = temp[0:4] + '-' + temp[4:6] + '-' + temp[6:8]
            release_date = str(temp)
            gameMetadata += 'Released:\n' + temp + '\n'
        else:
            release_date = 'N/A'
        print(release_date)

        if best_match_game.find('developer') is not None:
            temp = str(best_match_game.find('developer').text)
            developer = str(temp)
            gameMetadata += 'Developer:\n' + temp + '\n'
        else:
            developer = 'N/A'
        print(developer)

        if best_match_game.find('publisher') is not None:
            temp = str(best_match_game.find('publisher').text)
            publisher = str(temp)
            gameMetadata += 'Publisher:\n' + temp + '\n'
            publisher = 'N/A'
        print(publisher)

        if best_match_game.find('genre') is not None:
            temp = str(best_match_game.find('genre').text)
            genre = str(temp)
            gameMetadata += 'Genre:\n' + temp + '\n'
        else:
            genre = 'N/A'
        print(genre)
        
    else: 
        print("No close match found for game_name in the XML tree! RIP.")

    return gameMetadata, gameMetadataDesc

GAME_START_FILE = '/dev/shm/runcommand.info'
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

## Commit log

2023-02-06 Add blocking wait delay to prevent lockup
    [main.c]
2023-03-29 Fix parenthesis for receive_start_string
    [main.c]
2023-04-13 Fix start, end and stop string func
    Fixed functions always returning true regardless of serial input value
    [main.c]
2023-04-17 Active low button press
2023-04-21 Fix loop index for serial image reads
    [ssd1351.c]
2023-04-25 Pullup button_pin 6
2023-05-22 Graceful shutdown on power off
2023-06-01 Fix shutdown and reboot issue
    [main.c]
2023-06-02 Splashscreen on shutdown/message fix
    [main.c]
2023-06-02 Splashscreen on shutdown/reboot fix
    [ssd1351.c]
2023-06-03 Shorten splashscreen length on power down
    [main.c]
2023-06-04 Fix text centering & background issue
    [main.c]
2023-06-16 Fix x + 127 issue
    [ssd1351.c]
2026-08-05 Enhance image finding and logging in onstart script
    Added a function to find image files with multiple extensions and updated logging for screenshots, wheels, and box art instead of hard coding pngs

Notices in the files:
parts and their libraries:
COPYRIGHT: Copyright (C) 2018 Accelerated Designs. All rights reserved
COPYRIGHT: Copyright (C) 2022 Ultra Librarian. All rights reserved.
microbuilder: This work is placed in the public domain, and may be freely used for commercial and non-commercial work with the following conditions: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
